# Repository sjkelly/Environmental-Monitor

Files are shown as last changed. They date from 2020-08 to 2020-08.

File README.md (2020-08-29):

# Environmental Monitor

My home environmental monitor system.

## BOM

- [Adafruit HUZZAH32 – ESP32 Feather Board](https://www.adafruit.com/product/3591)
- [PM2.5 Air Quality Sensor and Breadboard Adapter Kit - PMS5003](https://www.adafruit.com/product/3686)
- [Adafruit Sensirion SHT31-D - Temperature & Humidity Sensor](https://www.adafruit.com/product/2857)
- [Adafruit CCS811 Air Quality Sensor Breakout - VOC and eCO2](https://www.adafruit.com/product/3566)

## Live Monitoring

[Adafruit IO](https://io.adafruit.com/sjkelly/dashboards/env-monitor)

## Wiring

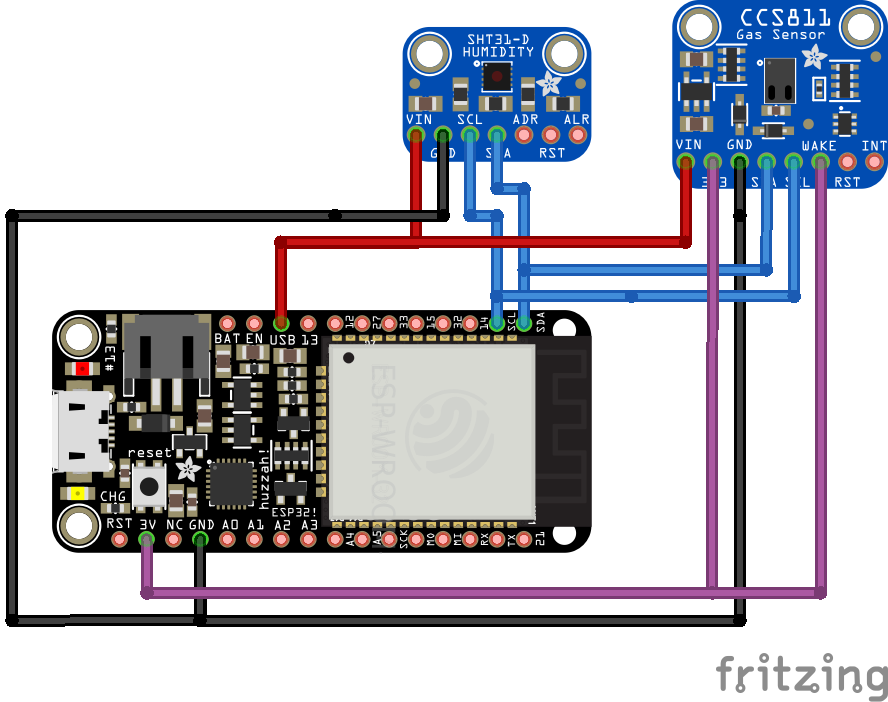
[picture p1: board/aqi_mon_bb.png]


## Notes on Sensors

This is still WIP, but some early observations.

### CCS811 - eCO2 and VOC

- needs a temperature and humidity measurement to have accuracy.
- the onboard temperature is no good.
- tends to fluctuate the first 48 hours after startup.

### SHT31

- Has onboard heater to reduce accumulated condensation
- Temp and Humidity oscillate, symptom of the above?
- Frequency to trigger heater?

## PM2.5 Sensor

Has several readings. Currently using PM standard. Also has environmental and PPM/0.1L.
Will it run off the 3.7V battery?

## ESP32

I used some tricks from [this article](https://savjee.be/2019/12/esp32-tips-to-increase-battery-life/). The ESP32 runs notably cooler
to the touch with a lower frequency and BT off.

## Observations

So far I have tested in my room.

### CO2
Unfortunately one of my room windows is right below a chimney. We burn natural gas here. There
are distinct spikes in CO2 detected if this window is open and the boiler is running. There
are similar rises when the gas stove is in use in the kitchen.

Overnight C02 levels also rise to around 1500PPM, unless a window is cracked in which case they are around 600-1000PPM.
Working from home, I spend easily 18-22 hours a day in my room. Air circulation is quite good and the CO2 levels generally stay
under 1000PPM. Nominal values seem to be around 600-800.

I have 7 house plants; spider, sanservia, bamboo, and pothos varieties. Only two are full size. I'd like to see how watering cycles
and growth affect CO2, and how quantity of plants affect the rate of drop in CO2.

### PM2.5
I have a HEPA filter over my AC and a standalone Coway filter. Both seem to keep PM2.5 <0.2.
I am curious to see how this changes in the winter when only the Coway is running.

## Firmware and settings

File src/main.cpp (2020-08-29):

#include "config_user.h"


#include <SPI.h>
#include <Wire.h>
#include <esp_bt.h>
#include <esp_wifi.h>
#include "driver/adc.h"

// Snesor Libs
#include "Adafruit_CCS811.h"
#include "Adafruit_PM25AQI.h"
#include "Adafruit_SHT31.h"


Adafruit_CCS811 ccs;
Adafruit_PM25AQI aqi = Adafruit_PM25AQI();
Adafruit_SHT31 sht31 = Adafruit_SHT31();

// set up the adafruit IO feeds
AdafruitIO_Feed *temperature = io.feed("temperature");
AdafruitIO_Feed *humidity = io.feed("humidity");
AdafruitIO_Feed *tvoc1 = io.feed("tvoc1");
AdafruitIO_Feed *eco2 = io.feed("eco2");
AdafruitIO_Feed *pm25 = io.feed("pm2-dot-5");
AdafruitIO_Feed *pm10 = io.feed("pm1-dot-0");
AdafruitIO_Feed *pm100 = io.feed("pm10");

//CCS
float eco2_read;
float tvoc_read;
float eco2_sum;
float tvoc_sum;

//PM25
float pm10_read;
float pm25_read;
float pm100_read;
float pm10_sum;
float pm25_sum;
float pm100_sum;

//SHT
float temp_read;
float humidity_read;
float temp_sum;
float humidity_sum;

int num_reads_ccs;
int num_reads_pm;
int num_reads_sht;

unsigned long last_mqtt_send;

#define SERIALOUT 1

void setup() {

  // ESP Power saving
  btStop();
  adc_power_off();
  esp_bt_controller_disable();
  setCpuFrequencyMhz(80);


  Serial1.begin(9600); //PM2.5 UART

  #if SERIALOUT
    Serial.begin(115200);

    // Init CCS
    if(!ccs.begin()){
        Serial.println("Failed to start sensor! Please check your wiring.");
        while(1);
    }

    if (! aqi.begin_UART(&Serial1)) { // connect to the sensor over hardware serial
        Serial.println("Could not find PM 2.5 sensor!");
        while (1) delay(10);
    }
    Serial.println("PM25 found!");
  #endif


  Serial.println("SHT31 test");
  if (! sht31.begin(0x44)) {   // Set to 0x45 for alternate i2c addr
    Serial.println("Couldn't find SHT31");
    while (1) delay(1);
  }

  Serial.print("Heater Enabled State: ");
  if (sht31.isHeaterEnabled())
    Serial.println("ENABLED");
  else
    Serial.println("DISABLED");

  sht31.heater(false);

  delay(500);

  //calibrate temperature sensor
  while(!ccs.available());
    ccs.setEnvironmentalData((int)sht31.readHumidity(),sht31.readTemperature());

  // Adafruit IO connect
  io.connect();

  // Start Tracking time
  last_mqtt_send = millis();
  num_reads_ccs = 0;
  num_reads_pm = 0;
}

void loop() {

  PM25_AQI_Data data;

  // io.run(); is required for all sketches.
  // it should always be present at the top of your loop
  // function. it keeps the client connected to
  // io.adafruit.com, and processes any incoming data.
  io.run();

  // Read CCS Sensor
  if(ccs.available()){
    if(!ccs.readData()){
      eco2_read = ccs.geteCO2();
      eco2_sum += eco2_read;
      tvoc_read = ccs.getTVOC();
      tvoc_sum += tvoc_read;

      num_reads_ccs += 1;

      #if SERIALOUT
        Serial.print("eCO2: ");
        Serial.print(eco2_read);

        Serial.print(" ppm, TVOC Avg: ");
        Serial.print(tvoc_read);
      #endif
    }
  }

  // Read AQI
  if (aqi.read(&data)) {

    num_reads_pm += 1;

    pm10_read = data.pm10_standard;
    pm25_read = data.pm25_standard;
    pm100_read = data.pm100_standard;

    pm100_sum += pm100_read;
    pm10_sum += pm10_read;
    pm25_sum += pm25_read;

    #if SERIALOUT
        Serial.println("AQI reading success");

        Serial.print(F("PM 1.0: ")); Serial.print(pm10_read);
        Serial.print(F("\t\tPM 2.5: ")); Serial.print(pm25_read);
        Serial.print(F("\t\tPM 10: ")); Serial.println(pm100_read);
    #endif
  }

  // Read SHT
  float temp_read = sht31.readTemperature();
  float humidity_read = sht31.readHumidity();

  if (! isnan(temp_read) && !isnan(humidity_read)) {  // check if 'is not a number'
    Serial.print("Temp *C = "); Serial.print(temp_read);
    Serial.print("Hum. % = "); Serial.println(humidity_read);
    temp_sum += temp_read;
    humidity_sum += humidity_read;
    num_reads_sht += 1;
  }

  // wait 30 seconds
  if(millis() - last_mqtt_send > 30000) {
    float eco2_avg = eco2_sum/num_reads_ccs;
    float tvoc_avg = tvoc_sum/num_reads_ccs;

    float temp_avg = temp_sum/num_reads_sht;
    float humidity_avg = humidity_sum/num_reads_sht;

    // Compensate CCS using SHT
    ccs.setEnvironmentalData((int)humidity_avg, temp_avg);

    float pm10_avg = pm10_sum/num_reads_pm;
    float pm25_avg = pm25_sum/num_reads_pm;
    float pm100_avg = pm100_sum/num_reads_pm;

    eco2->save(eco2_avg);
    tvoc1->save(tvoc_avg);
    temperature->save(temp_avg);
    humidity->save(humidity_avg);
    pm10->save(pm10_avg);
    pm25->save(pm25_avg);
    pm100->save(pm100_avg);

    last_mqtt_send = millis();

    #if SERIALOUT
      Serial.println("Sent MQTT Msg:");
      Serial.print("Number of CCS readings: ");
      Serial.println(num_reads_ccs);
      Serial.print("Number of PM readings: ");
      Serial.println(num_reads_pm);
      Serial.print("Number of SHT readings: ");
      Serial.println(num_reads_sht);
      Serial.print("eCO2 Avg: ");
      Serial.print(eco2_avg);

      Serial.print(" ppm, TVOC: ");
      Serial.print(tvoc_avg);

      Serial.print(" ppb, Temp:");
      Serial.println(temp_avg);

      Serial.print("PM1.0: ");
      Serial.print(pm10_avg);

      Serial.print(" PM2.5:");
      Serial.print(pm25_avg);

      Serial.print("PM10: ");
      Serial.println(pm100_avg);
    #endif

    num_reads_ccs = 0;
    num_reads_pm = 0;
    num_reads_sht = 0;
    eco2_sum = 0;
    temp_sum = 0;
    humidity_sum = 0;
    tvoc_sum = 0;
    pm100_sum = 0;
    pm10_sum = 0;
    pm25_sum = 0;
  }

}

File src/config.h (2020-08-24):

/************************ Adafruit IO Config *******************************/

// visit io.adafruit.com if you need to create an account,
// or if you need your Adafruit IO key.
#define IO_USERNAME  "user"
#define IO_KEY       "apikey"

/******************************* WIFI **************************************/

// the AdafruitIO_WiFi client will work with the following boards:
//   - HUZZAH ESP8266 Breakout -> https://www.adafruit.com/products/2471
//   - Feather HUZZAH ESP8266 -> https://www.adafruit.com/products/2821
//   - Feather HUZZAH ESP32 -> https://www.adafruit.com/product/3405
//   - Feather M0 WiFi -> https://www.adafruit.com/products/3010
//   - Feather WICED -> https://www.adafruit.com/products/3056
//   - Adafruit PyPortal -> https://www.adafruit.com/product/4116
//   - Adafruit Metro M4 Express AirLift Lite ->
//   https://www.adafruit.com/product/4000
//   - Adafruit AirLift Breakout -> https://www.adafruit.com/product/4201
//   - Adafruit AirLift Shield -> https://www.adafruit.com/product/4285
//   - Adafruit AirLift FeatherWing -> https://www.adafruit.com/product/4264

#define WIFI_SSID "ssid"
#define WIFI_PASS "pass"

// uncomment the following line if you are using airlift
// #define USE_AIRLIFT

// uncomment the following line if you are using winc1500
// #define USE_WINC1500

// comment out the following lines if you are using fona or ethernet
#include "AdafruitIO_WiFi.h"

#if defined(USE_AIRLIFT) || defined(ADAFRUIT_METRO_M4_AIRLIFT_LITE) ||         \
    defined(ADAFRUIT_PYPORTAL)
// Configure the pins used for the ESP32 connection
#if !defined(SPIWIFI_SS) // if the wifi definition isnt in the board variant
// Don't change the names of these #define's! they match the variant ones
#define SPIWIFI SPI
#define SPIWIFI_SS 10 // Chip select pin
#define NINA_ACK 9    // a.k.a BUSY or READY pin
#define NINA_RESETN 6 // Reset pin
#define NINA_GPIO0 -1 // Not connected
#endif
AdafruitIO_WiFi io(IO_USERNAME, IO_KEY, WIFI_SSID, WIFI_PASS, SPIWIFI_SS,
                   NINA_ACK, NINA_RESETN, NINA_GPIO0, &SPIWIFI);
#else
AdafruitIO_WiFi io(IO_USERNAME, IO_KEY, WIFI_SSID, WIFI_PASS);
#endif
/******************************* FONA **************************************/

// the AdafruitIO_FONA client will work with the following boards:
//   - Feather 32u4 FONA -> https://www.adafruit.com/product/3027

// uncomment the following two lines for 32u4 FONA,
// and comment out the AdafruitIO_WiFi client in the WIFI section
// #include "AdafruitIO_FONA.h"
// AdafruitIO_FONA io(IO_USERNAME, IO_KEY);

/**************************** ETHERNET ************************************/

// the AdafruitIO_Ethernet client will work with the following boards:
//   - Ethernet FeatherWing -> https://www.adafruit.com/products/3201

// uncomment the following two lines for ethernet,
// and comment out the AdafruitIO_WiFi client in the WIFI section
// #include "AdafruitIO_Ethernet.h"
// AdafruitIO_Ethernet io(IO_USERNAME, IO_KEY);

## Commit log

2020-08-29 add SHT and PM sensor
2020-08-29 add some notes and BOM
2020-08-29 add board wiring
    [aqi_mon.fzz]
2022-01-26 pin deps
